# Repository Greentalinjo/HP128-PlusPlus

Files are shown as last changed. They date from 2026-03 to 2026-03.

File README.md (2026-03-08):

# HP 128 Laser Wired Mouse Reverse Engineering 🖱️🔍

> **Disclaimer:** This project is strictly for **educational purposes**. The HP 128 laser mouse and its original design are the intellectual property of HP. This repository serves as a study in hardware reverse engineering, component analysis, and PCB layout techniques.

## What this is
This project is a complete, bottom-up reverse engineering of the HP 128 laser wired mouse. The goal of this research was to create a near-perfect, 1:1 functional clone of the original PCB. Every trace, jumper, component footprint, and silkscreen marking has been meticulously recreated to match the original factory board.

### Side-By-Side

#### Back:

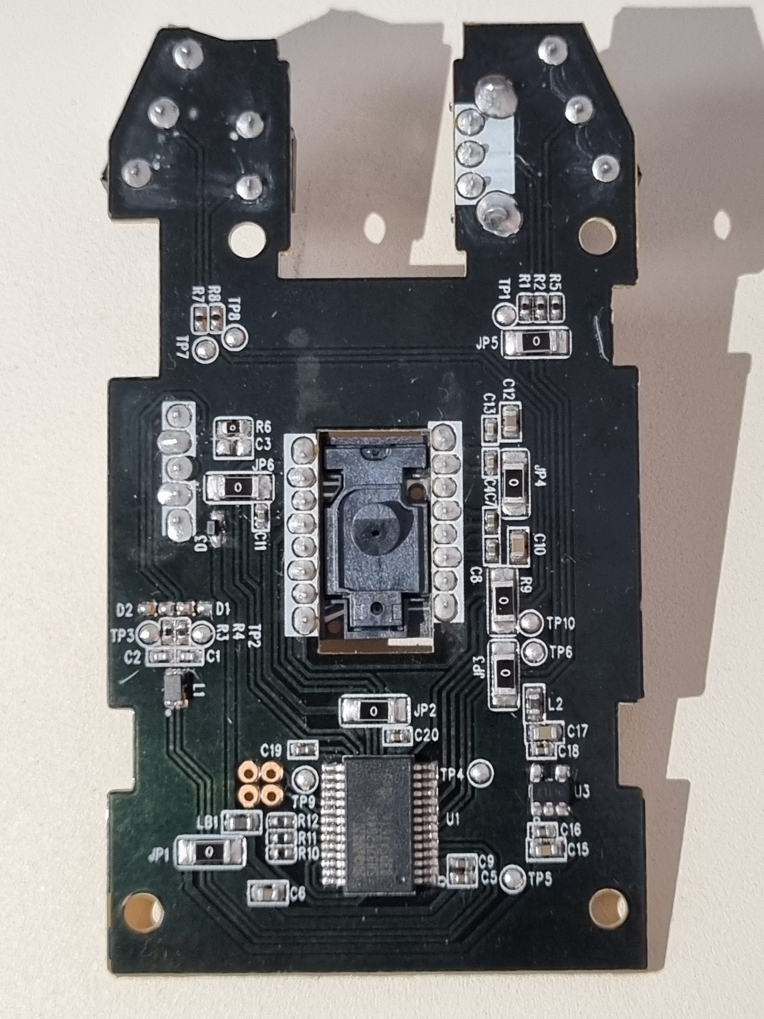
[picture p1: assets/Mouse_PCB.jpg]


#### Front:

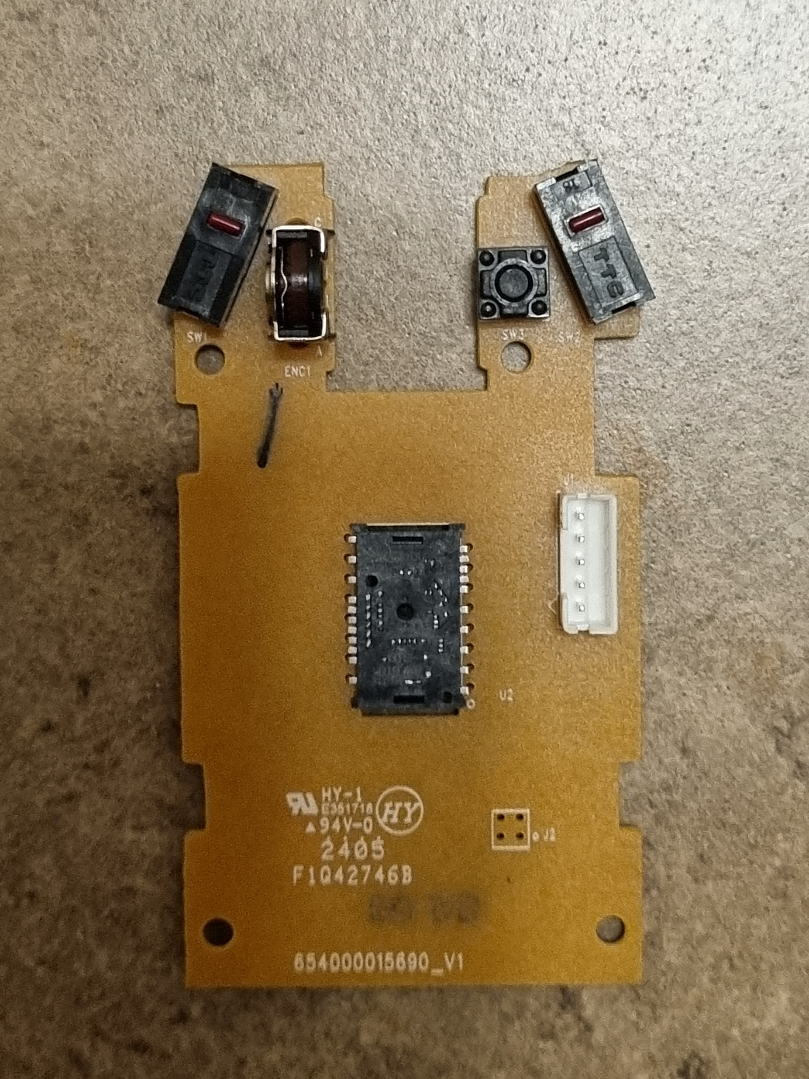
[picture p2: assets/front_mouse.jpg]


## Teardown

<table>
  <thead>
    <tr>
      <th align="center" width="50%">1</th>
      <th align="center" width="50%">2</th>
    </tr>
  </thead>
  <tbody>
    <tr>
      <td align="center" valign="middle">
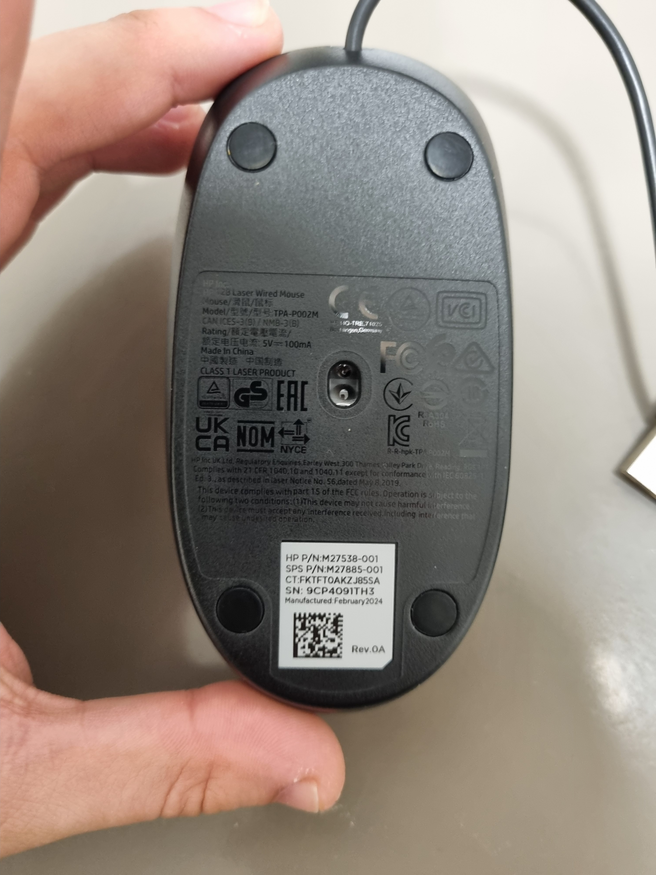
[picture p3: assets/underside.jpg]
        
      </td>
      <td align="center" valign="middle">
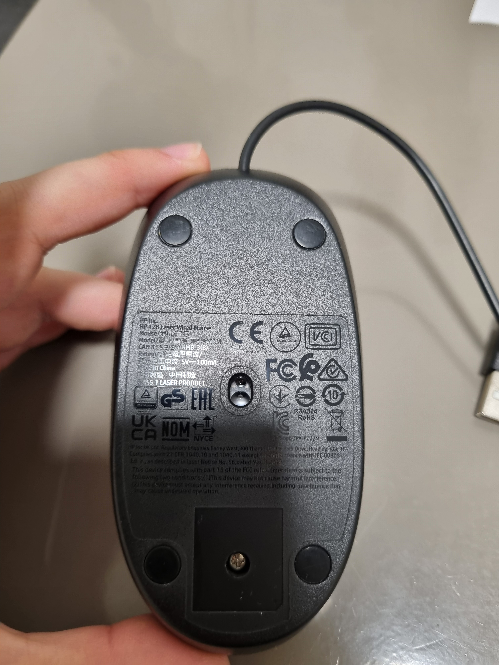
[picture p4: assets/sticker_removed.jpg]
        
      </td>
    </tr>
    <tr>
      <td valign="top">
        <h3 align="center">Initial inspection</h3>
        <p>The writing on the mouse is documenting identifying details, including the model number "TPA-P002M," a specific serial number, and the manufacturing date of "February 2024". The mouse is in its initial, fully assembled state.</p>
      </td>
      <td valign="top">
        <h3 align="center">Bottom Screw Access and Disassembly</h3>
        <p>Remove the sticker to reveal the primary bottom screw. Unscrew the screw and take the unit apart.</p>
      </td>
    </tr>
    <tr>
      <th align="center">3</th>
      <th align="center">4</th>
    </tr>
    <tr>
      <td align="center" valign="middle">
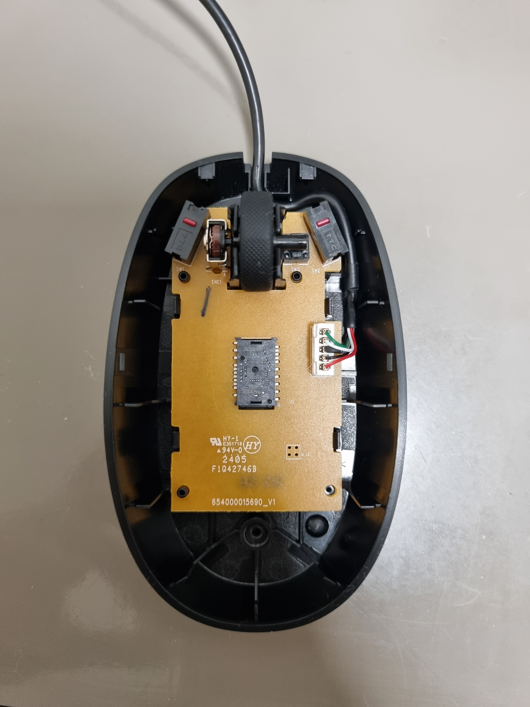
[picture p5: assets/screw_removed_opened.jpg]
        
      </td>
      <td align="center" valign="middle">
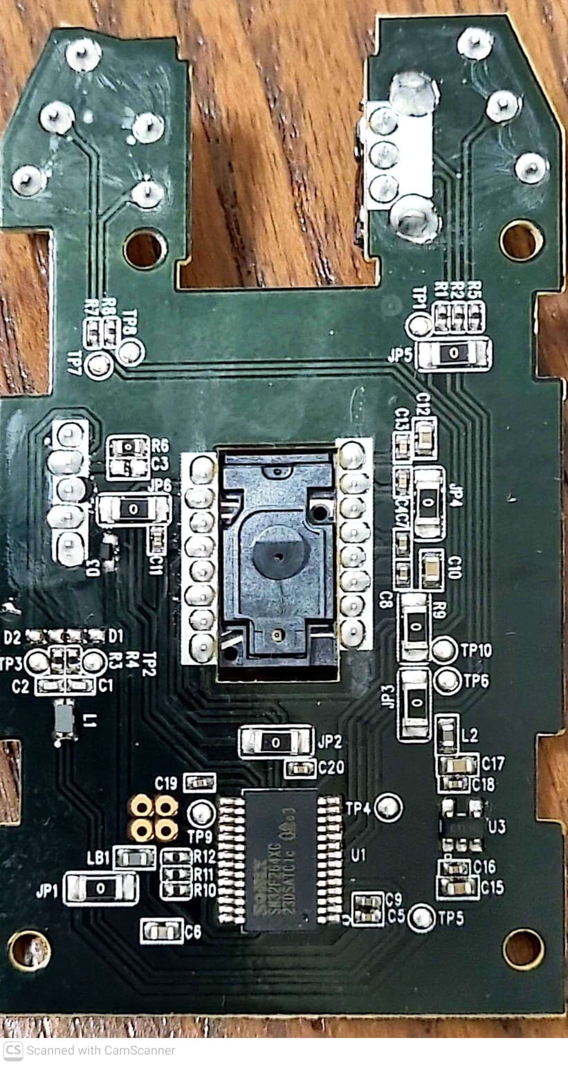
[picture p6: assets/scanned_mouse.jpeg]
        
      </td>
    </tr>
    <tr>
      <td valign="top">
        <h3 align="center">PCB top side</h3>
        <p>After removing the screw and separating the top and bottom shells, the top of the pcb is revealed. The visible parts are the microswitches, the scroll wheel and its rotary encoder, the scroll wheel button, the USB connector, and the laser sensor.</p>
      </td>
      <td valign="top">
        <h3 align="center">PCB bottom side</h3>
        <p>Flipping the board its finally possible to see the entire circuit. Including but not limited to the MCU, LDO, underside of the laser sensor, etc.</p>
      </td>
    </tr>
  </tbody>
</table>

## Component Analysis

The two most interesting components are obviously the MCU and the laser sensor.

### MCU - SN32F264X (SSOP28)

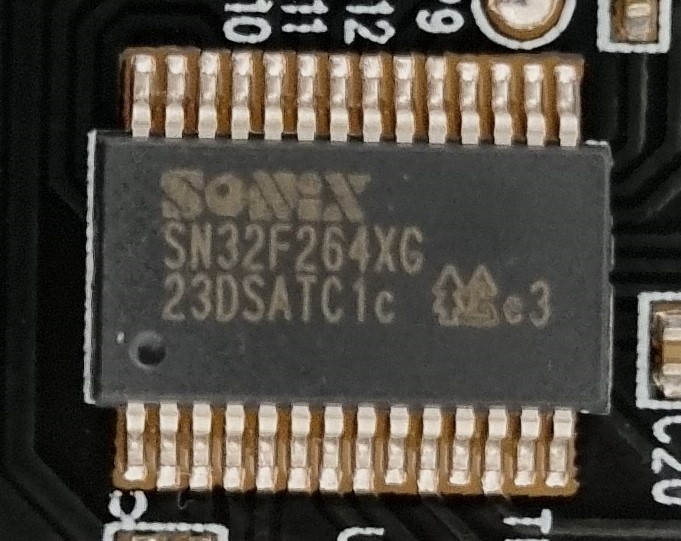
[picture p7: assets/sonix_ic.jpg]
sonix_ic


This MCU is a 32-Bit Cortex-M0 Micro-Controller manufactured by Sonix:

https://www.sonix.com.tw/article-en-998-24755

Whilst the datasheet is available and can be downloaded from the linked web page, a symbol for KiCad was not. So I had to create my own symbol for it.

### Laser sensor - PMW3610DM-SUDU

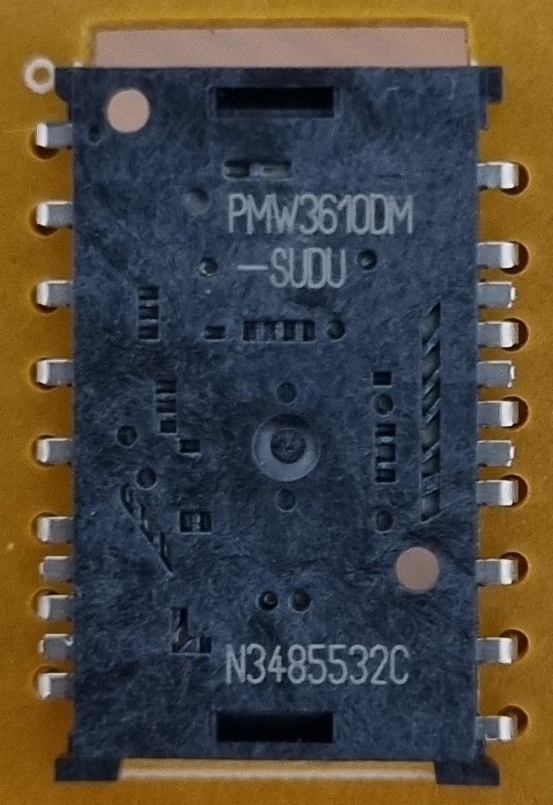
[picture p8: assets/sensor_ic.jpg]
sensor_ic


This is a laser sensor with a janky footprint that luckily was already created by two github users:

https://github.com/Good-Great-Grand-Wonderful/pmw3610dm-sudu

https://github.com/siderakb/pmw3610-pcb

Its datasheet is also readily available here:

https://www.epsglobal.com/Media-Library/EPSGlobal/Products/files/pixart/PMW3610DM-SUDU.pdf?ext=.pdf

## Schematic Extraction
A few hours, a digital multimeter in continuity mode, and some close-up images later a schematic was successfully extracted:

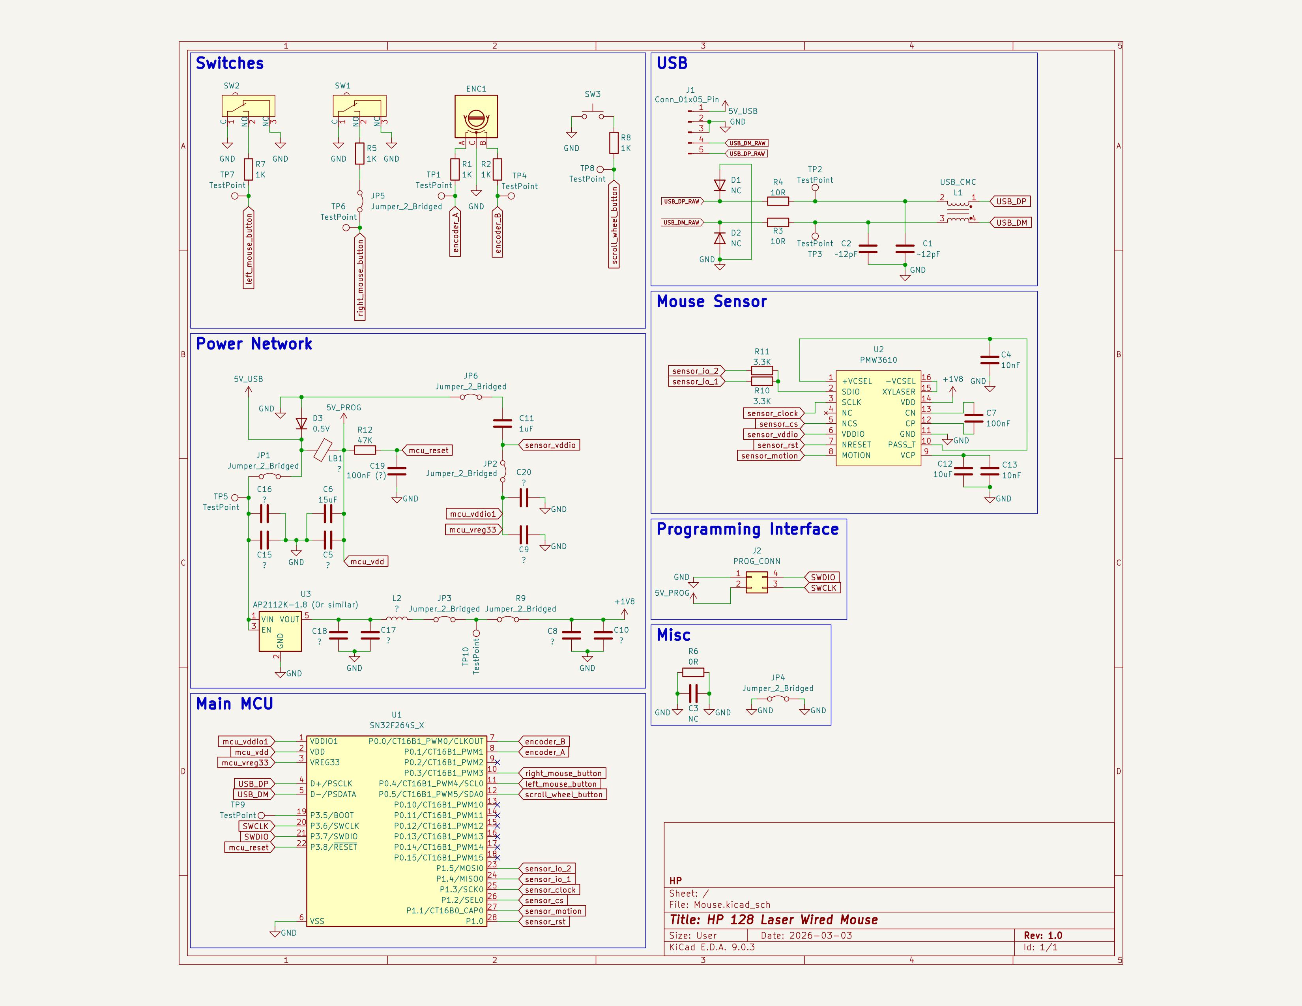
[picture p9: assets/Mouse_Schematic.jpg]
Mouse_Schematic


Some component values were not measured due to the need to de-solder them, and at the time of me working on this project I could not find the time to do so. These missing values are left as an exercise for the reader as is commonly said.

## 1:1 PCB Recreation

To recreate the PCB, A close-up image was adjusted to the correct scale and proportions using a website called Photopea:

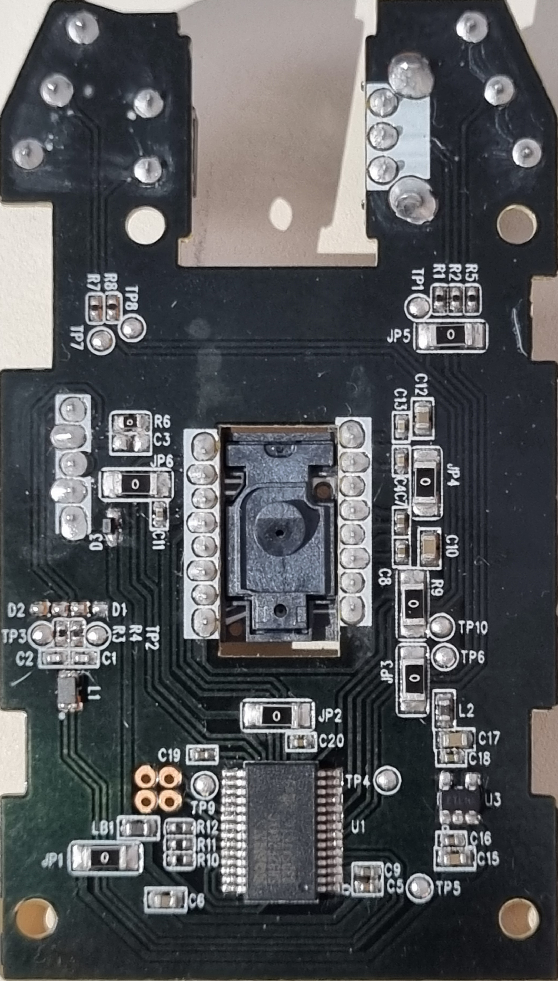
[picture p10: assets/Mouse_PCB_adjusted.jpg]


Then, the image was placed in the PCB view in KiCad, and all of the components and traces were placed according to the image.

The most attention demanding part were the little things - The silkscreen writings, font sizes, component outlines, etc.

## What's next?
If you want to fabricate your own board or study the layout feel free to do so. 

Once I assemble this board there are a few interesting research directions I would like to go down with the Sonix MCU, and perhaps integrate wireless connectivity for the mouse as well.

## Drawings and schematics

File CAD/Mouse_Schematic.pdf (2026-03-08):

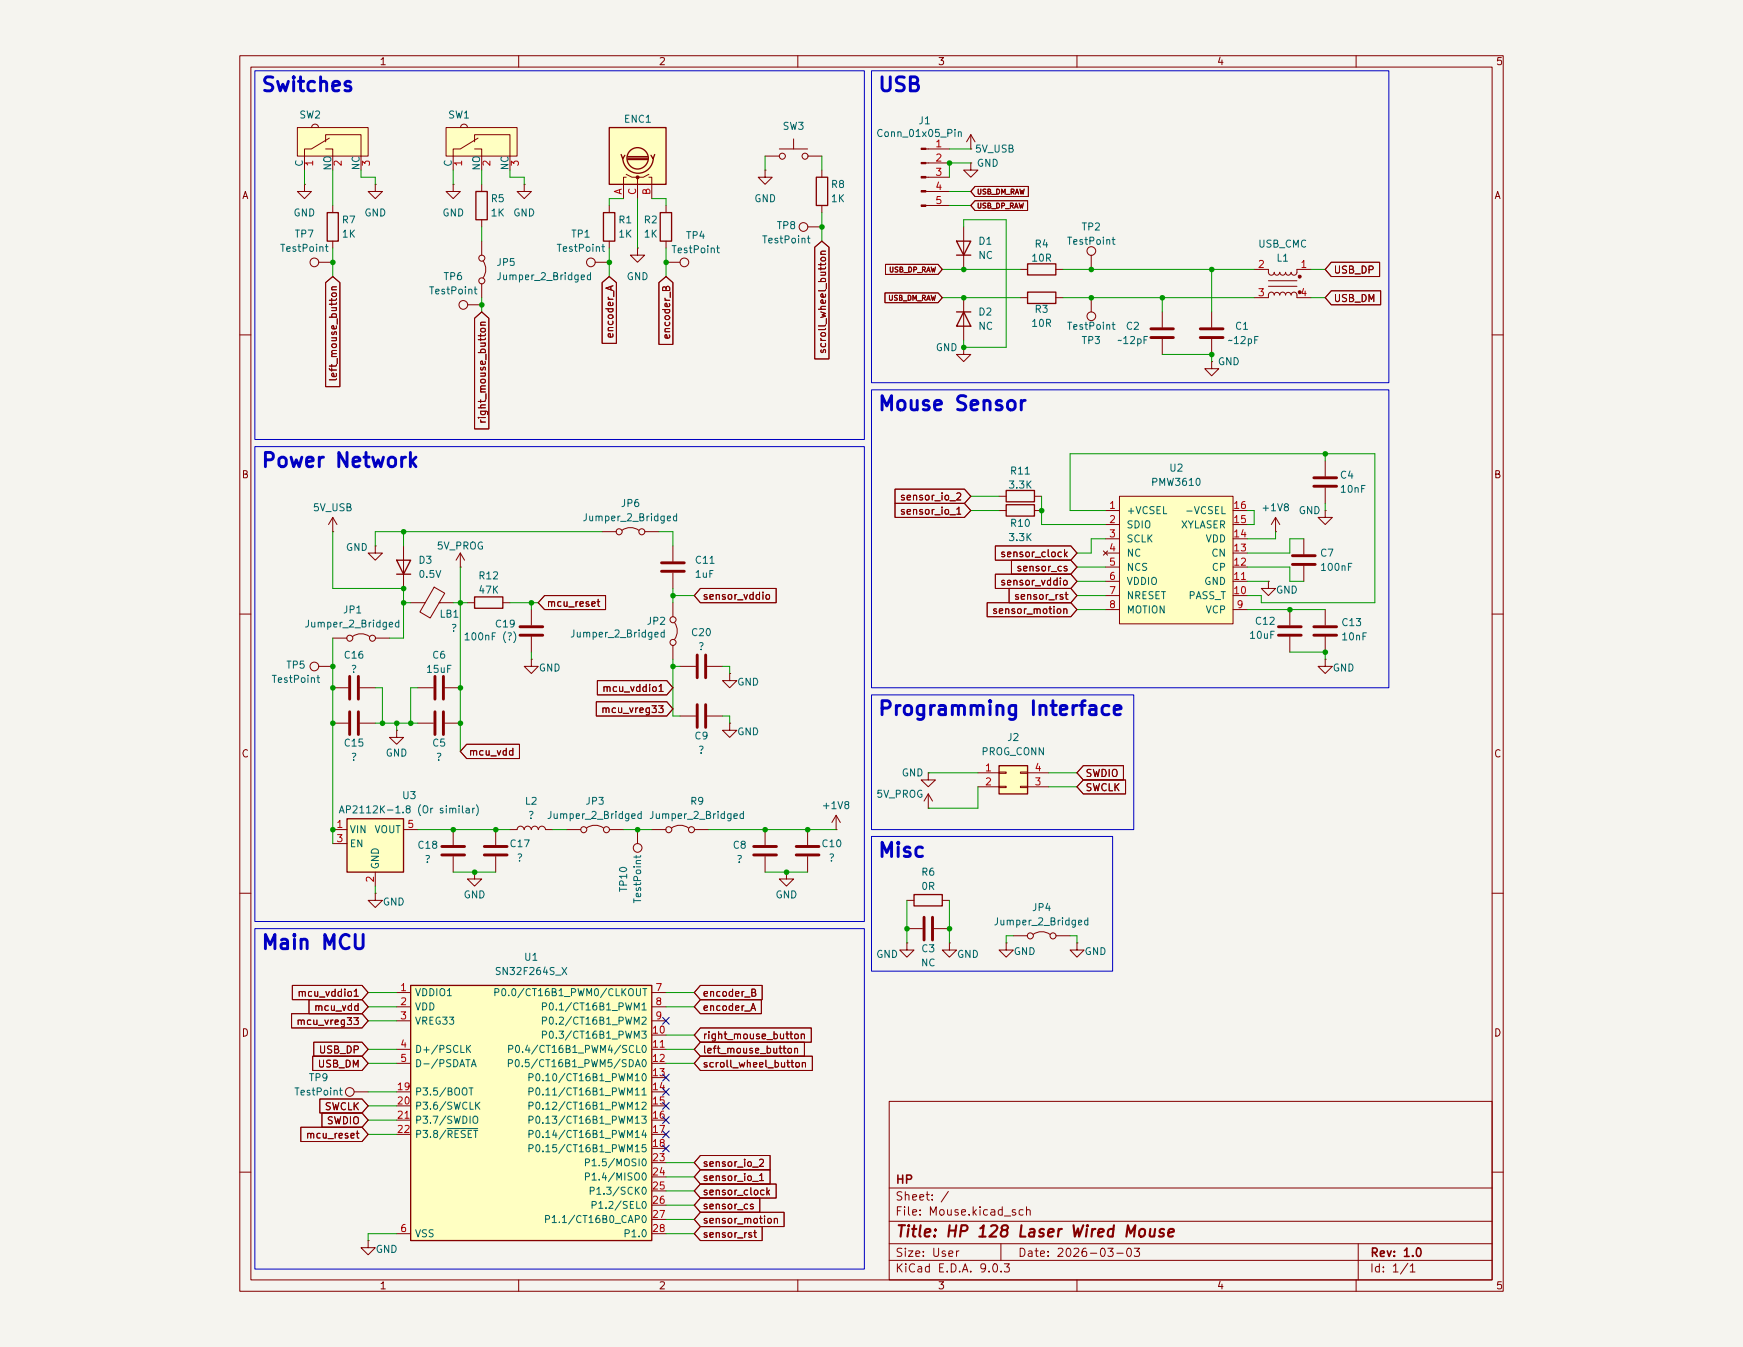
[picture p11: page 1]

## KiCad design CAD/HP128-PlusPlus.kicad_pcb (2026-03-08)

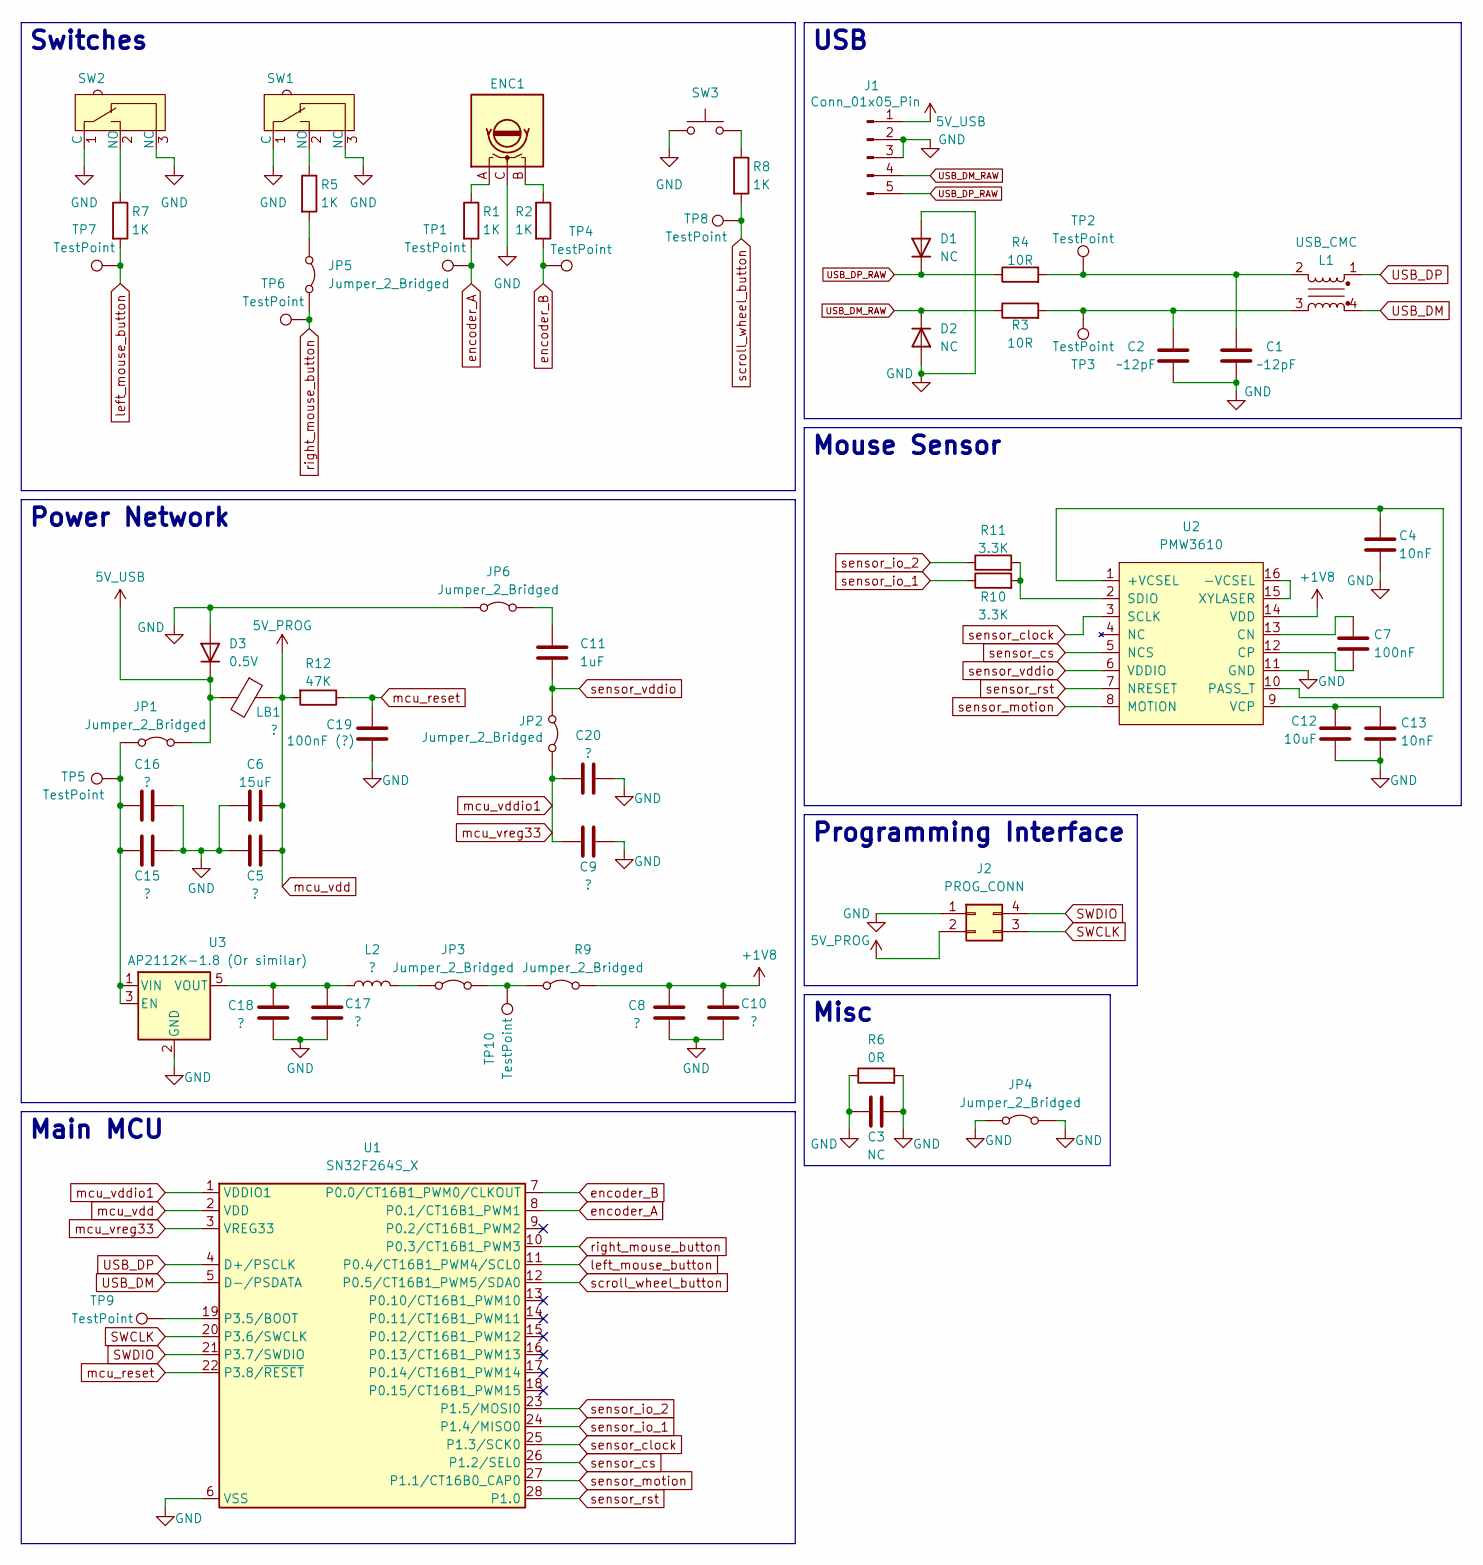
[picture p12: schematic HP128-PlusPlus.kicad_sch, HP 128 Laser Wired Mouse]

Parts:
C1, C2: ~12pF; C_0402_1005Metric
C3: NC; C_0603_1608Metric
C4, C13: 10nF; C_0402_1005Metric
C5, C8, C9, C16, C18, C20: ?; C_0402_1005Metric
C6: 15uF; C_0603_1608Metric
C7: 100nF; C_0402_1005Metric
C10, C15, C17: ?; C_0603_1608Metric
C11: 1uF; C_0402_1005Metric
C12: 10uF; C_0603_1608Metric
C19: 100nF (?); C_0402_1005Metric
D1, D2: NC; D_SOD-523
D3: 0.5V; D_SOD-523
ENC1: RotaryEncoder; RotaryEncoder_TTC_Staggered
J1: Conn_01x05_Pin; JST_PH_B5B-PH-K_1x05_P2.00mm_Vertical
J2: PROG_CONN; PinHeader_2x02_P1.75mm
JP1, JP2, JP3, JP4, JP5, JP6: Jumper_2_Bridged; R_1206_3216Metric
L1: USB_CMC; L_CommonModeChoke_Coilcraft_0805USB
L2: ?; L_0603_1608Metric
LB1: ?; L_0603_1608Metric
R1, R2, R5, R7, R8: 1K; R_0402_1005Metric
R3, R4: 10R; R_0402_1005Metric
R6: 0R; R_0603_1608Metric
R9: Jumper_2_Bridged; R_1206_3216Metric
R10, R11: 3.3K; R_0402_1005Metric
R12: 47K; R_0402_1005Metric
SW1, SW2: SW_SPDT; SW_Micro_Switch
SW3: SW_Push; SW_Tactile_6x6mm_2Pin
TP1, TP2, TP3, TP4, TP5, TP6, TP7, TP8, TP9, TP10: TestPoint; TestPoint_Pad_D1.5mm
U1: SN32F264S_X; SSOP-28_5.3x10.2mm_P0.65mm
U2: PMW3610; PMW3610DM-SUDU 16Pin
U3: AP2112K-1.8 (Or similar); SOT-23-5

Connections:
5V_USB: D3.1 (K), J1.1, JP1.2 (B), LB1.2
+1V8: C8.2, C10.2, R9.2 (B), U2.14 (VDD)
GND: C1.2, C2.2, C3.1, C3.2, C4.2, C5.1, C6.1, C8.1, C9.1, C10.1, C12.2, C13.2, C15.2, C16.2, C17.1, C18.1, C19.1, C20.2, D1.2 (A), D2.2 (A), D3.2 (A), ENC1.C, ENC1.MH1, ENC1.MH2, J1.2, J1.3, J2.1, JP4.1 (A), JP4.2 (B), JP6.1 (A), R6.1, R6.2, SW1.1 (C), SW1.3 (NC), SW2.1 (C), SW2.3 (NC), SW3.1, U1.6 (VSS), U2.11 (GND), U3.2 (GND)
unnamed: C1.1, L1.2, R4.2, TP2.1
unnamed: C2.1, L1.3, R3.2, TP3.1
unnamed: C15.1, C16.1, JP1.1 (A), TP5.1, U3.1 (VIN), U3.3 (EN)
unnamed: JP3.1 (A), L2.2
unnamed: JP3.2 (B), R9.1 (A), TP10.1
unnamed: JP5.1 (A), R5.2
unnamed: C11.1, JP6.2 (B)
unnamed: ENC1.A, R1.1
unnamed: ENC1.B, R2.1
unnamed: R8.1, SW3.2
unnamed: TP9.1, U1.19 (P3.5/BOOT)
unnamed: C4.1, U2.1 (+VCSEL), U2.10 (PASS_T)
unnamed: U2.15 (XYLASER), U2.16 (-VCSEL)
unnamed: C7.1, U2.13 (CN)
unnamed: C7.2, U2.12 (CP)
unnamed: R10.2, R11.2, U2.2 (SDIO)
unnamed: C12.1, C13.1, U2.9 (VCP)
unnamed: C17.2, C18.2, L2.1, U3.5 (VOUT)
unnamed: R7.1, SW2.2 (NO)
unnamed: R5.1, SW1.2 (NO)
SWCLK: J2.3, U1.20 (P3.6/SWCLK)
SWDIO: J2.4, U1.21 (P3.7/SWDIO)
USB_DM: L1.4, U1.5 (D-/PSDATA)
USB_DM_RAW: D2.1 (K), J1.4, R3.1
USB_DP: L1.1, U1.4 (D+/PSCLK)
USB_DP_RAW: D1.1 (K), J1.5, R4.1
encoder_A: R1.2, TP1.1, U1.8 (P0.1/CT16B1_PWM1)
encoder_B: R2.2, TP4.1, U1.7 (P0.0/CT16B1_PWM0/CLKOUT)
left_mouse_button: R7.2, TP7.1, U1.11 (P0.4/CT16B1_PWM4/SCL0)
mcu_reset: C19.2, R12.1, U1.22 (P3.8/~RESET)
mcu_vdd: C5.2, C6.2, J2.2, LB1.1, R12.2, U1.2 (VDD)
mcu_vddio1: C9.2, C20.1, JP2.2 (B), U1.1 (VDDIO1), U1.3 (VREG33)
right_mouse_button: JP5.2 (B), TP6.1, U1.10 (P0.3/CT16B1_PWM3)
scroll_wheel_button: R8.2, TP8.1, U1.12 (P0.5/CT16B1_PWM5/SDA0)
sensor_clock: U1.25 (P1.3/SCK0), U2.3 (SCLK)
sensor_cs: U1.26 (P1.2/SEL0), U2.5 (NCS)
sensor_io_1: R10.1, U1.24 (P1.4/MISO0)
sensor_io_2: R11.1, U1.23 (P1.5/MOSI0)
sensor_motion: U1.27 (P1.1/CT16B0_CAP0), U2.8 (MOTION)
sensor_rst: U1.28 (P1.0), U2.7 (NRESET)
sensor_vddio: C11.2, JP2.1 (A), U2.6 (VDDIO)

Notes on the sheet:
Mouse Sensor
USB
Programming Interface
Power Network
Misc
Switches
Main MCU

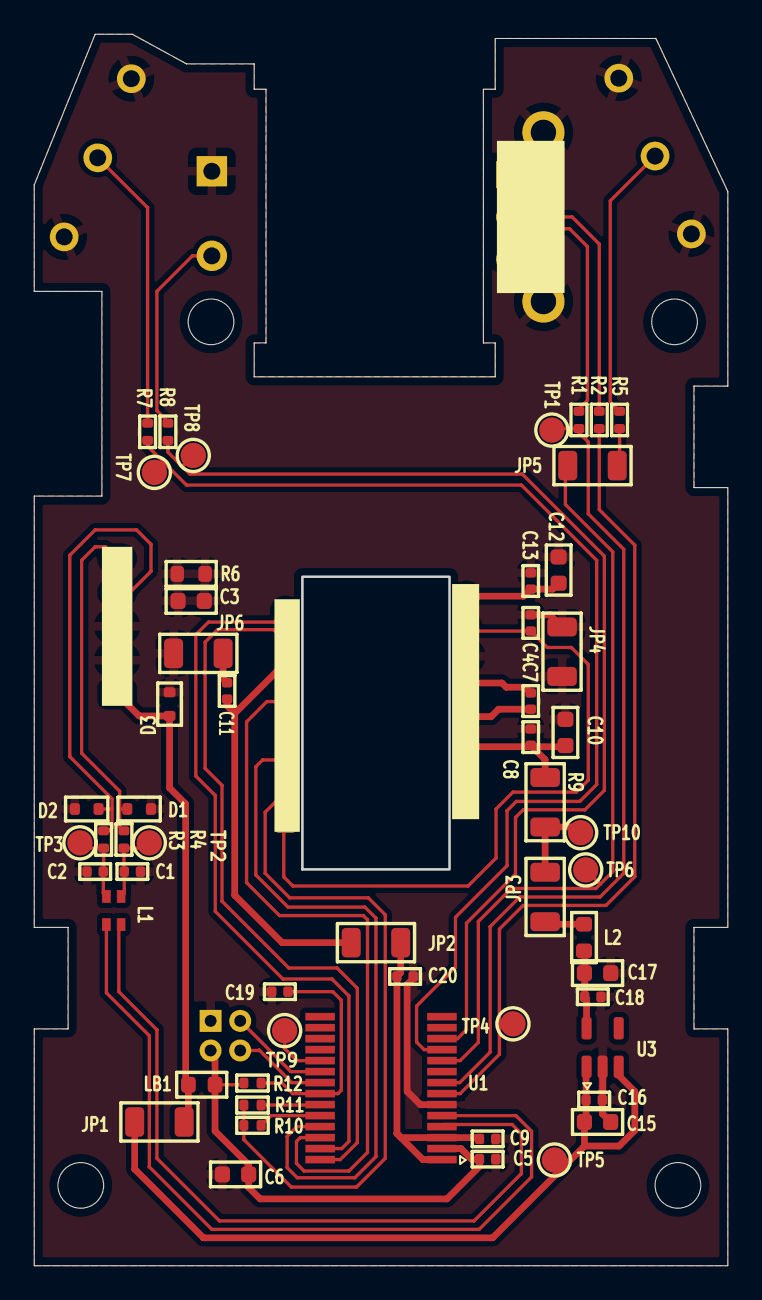
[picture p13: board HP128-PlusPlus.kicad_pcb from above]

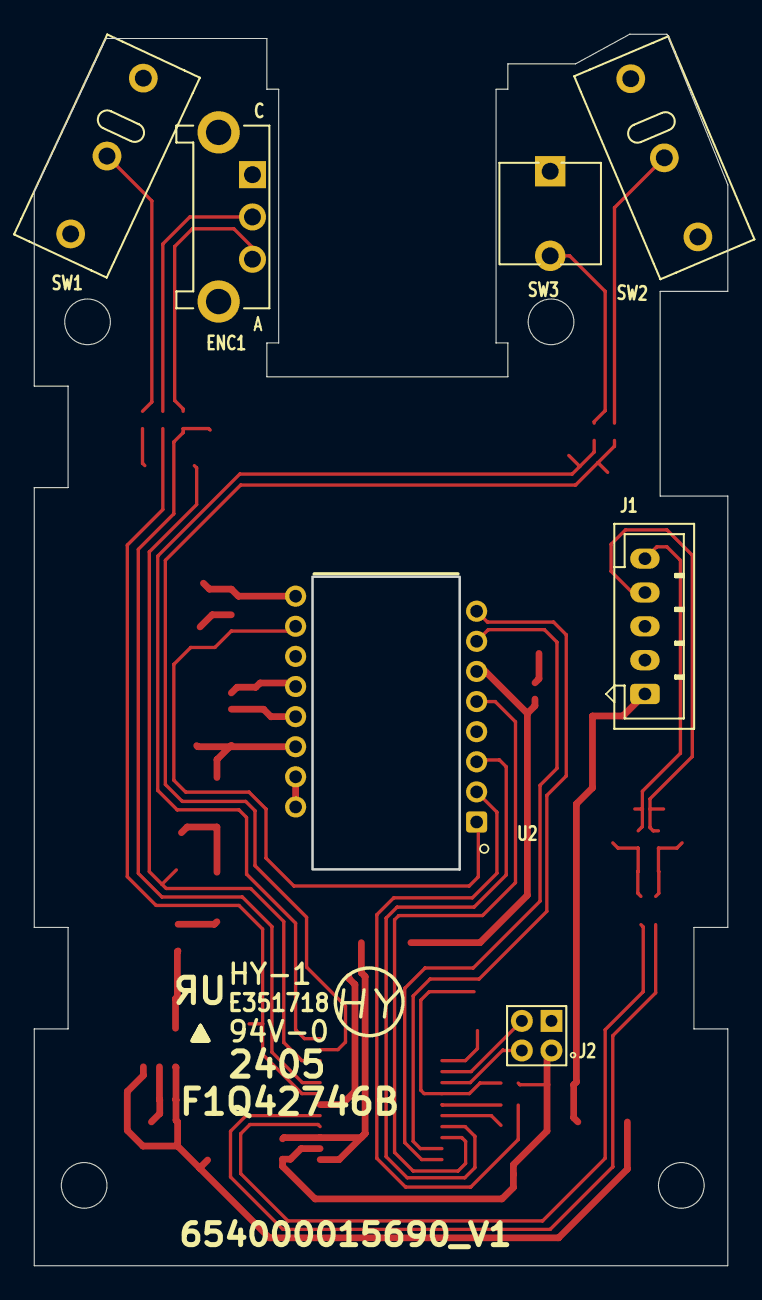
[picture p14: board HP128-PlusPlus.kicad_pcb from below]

Board: 2 copper layers, 41.0 x 72.8 mm, 62 parts (7 on the bottom side), 44 nets.
